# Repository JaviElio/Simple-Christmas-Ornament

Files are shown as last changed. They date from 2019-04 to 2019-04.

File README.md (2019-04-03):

# Simple-Christmas-Ornament
Christmas Ornament

Based on this project:

	- Title:	ESP8266 Christmas Ornaments!
	- Author:	Sean Hodgins
	- Link:		https://www.instructables.com/id/ESP8266-Christmas-Ornaments/

**BOM:**

(1) Attiny85

(3) WS2812

(1) DC/DC Step up converter ME2108

(1) Buzzer MLT-8530

(1) BC817

(1) SI2302

(1) Push Button

(1) [SMD AAA Batery Holder](https://www.aliexpress.com/item/5Pcs-lot-1-AAA-Battery-Holder-SMD-SMT-High-Quality-Battery-Box-With-Bronze-Pins-TBH/32795495670.html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,searchweb201602_5_10065_10068_10547_319_10891_317_10548_10696_10084_453_454_10083_10618_10307_10820_10821_10301_10303_537_536_10059_10884_10887_321_322_10103,searchweb201603_51,ppcSwitch_0&algo_expid=1f16c75a-10c3-4c96-85c8-67561e371a74-2&algo_pvid=1f16c75a-10c3-4c96-85c8-67561e371a74&transAbTest=ae803_3)

(1) Schottky Diode

(1) M7 Diode

(1) 47uF Capacitor

(1) 0.1uF Capacitor 

(1) 470 Ohm Resistor

(1) 10 kOhm Resistor

**SCHEMATIC:**

 [Schematic PDF](https://github.com/JaviElio/Simple-Christmas-Ornament/blob/master/Schematic.pdf)

**FEATURES:**

This Ornaments plays a song every time the button is pressed. Leds changes its color to the rhythm of the song.
Attiny85 goes to deep sleep to save energy.

**PICTURES**

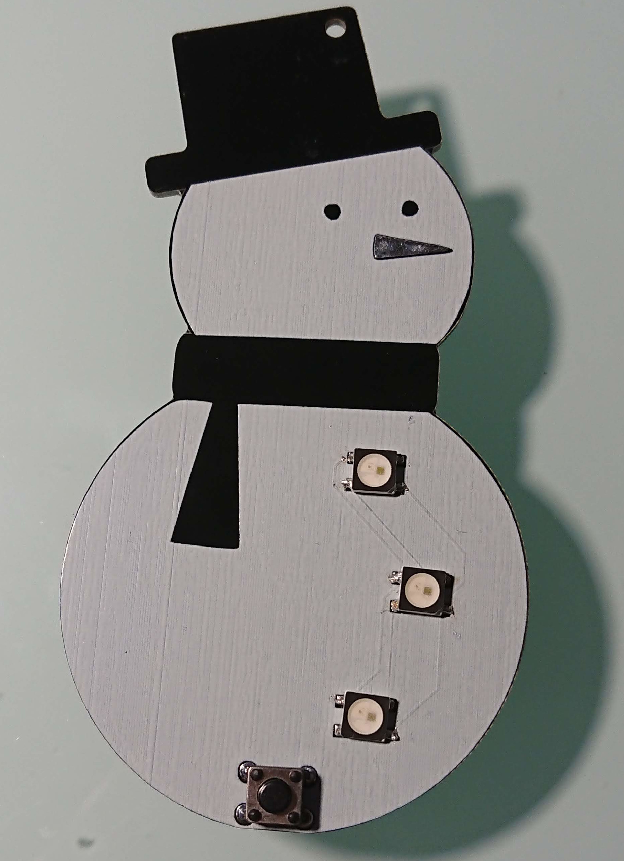
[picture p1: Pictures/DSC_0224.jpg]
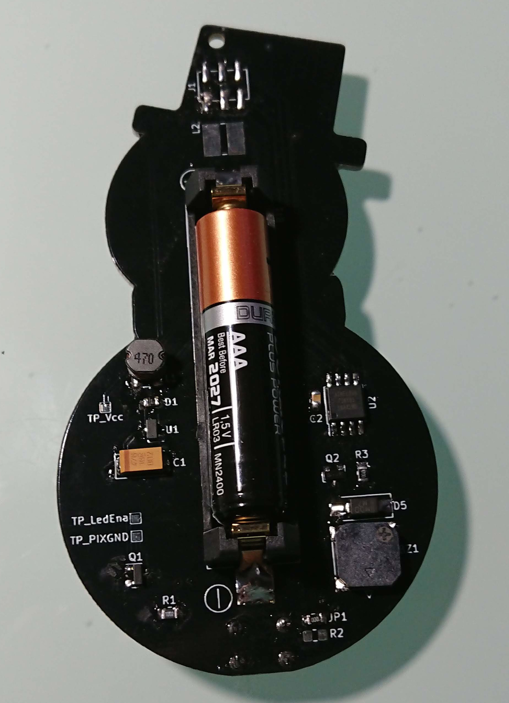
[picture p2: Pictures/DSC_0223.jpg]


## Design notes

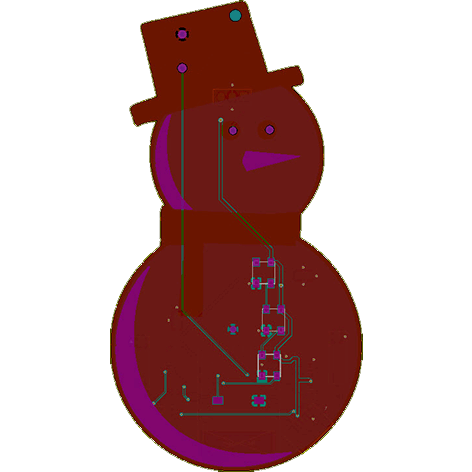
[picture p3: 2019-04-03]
Pictures/frosty.gif

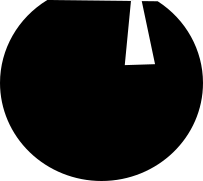
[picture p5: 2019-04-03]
Pictures/Frosty_Body.png

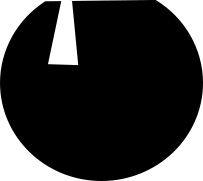
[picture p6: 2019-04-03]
Pictures/Frosty_Body.bmp

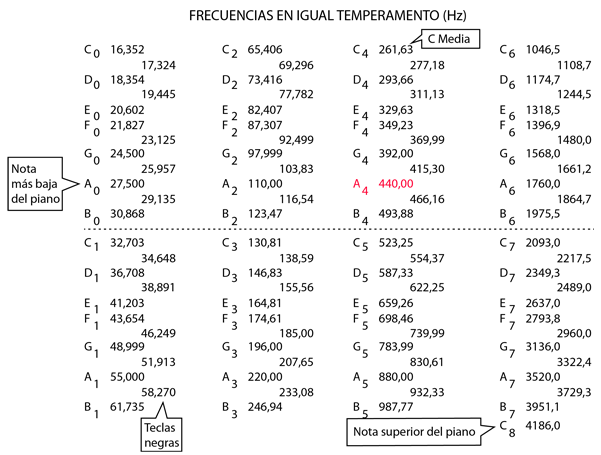
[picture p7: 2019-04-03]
Datasheets/etfreq.png

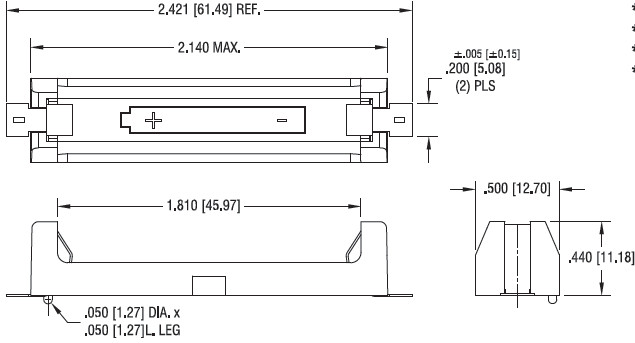
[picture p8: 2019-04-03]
Datasheets/AAA-Battery-Holder-SMD.jpg

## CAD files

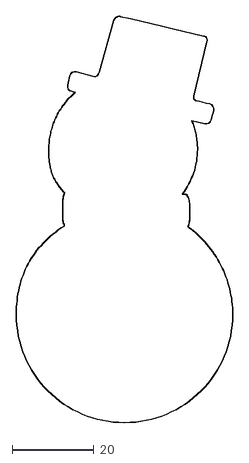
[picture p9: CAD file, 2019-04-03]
Pictures/PCB.dxf
52.8 x 99.1

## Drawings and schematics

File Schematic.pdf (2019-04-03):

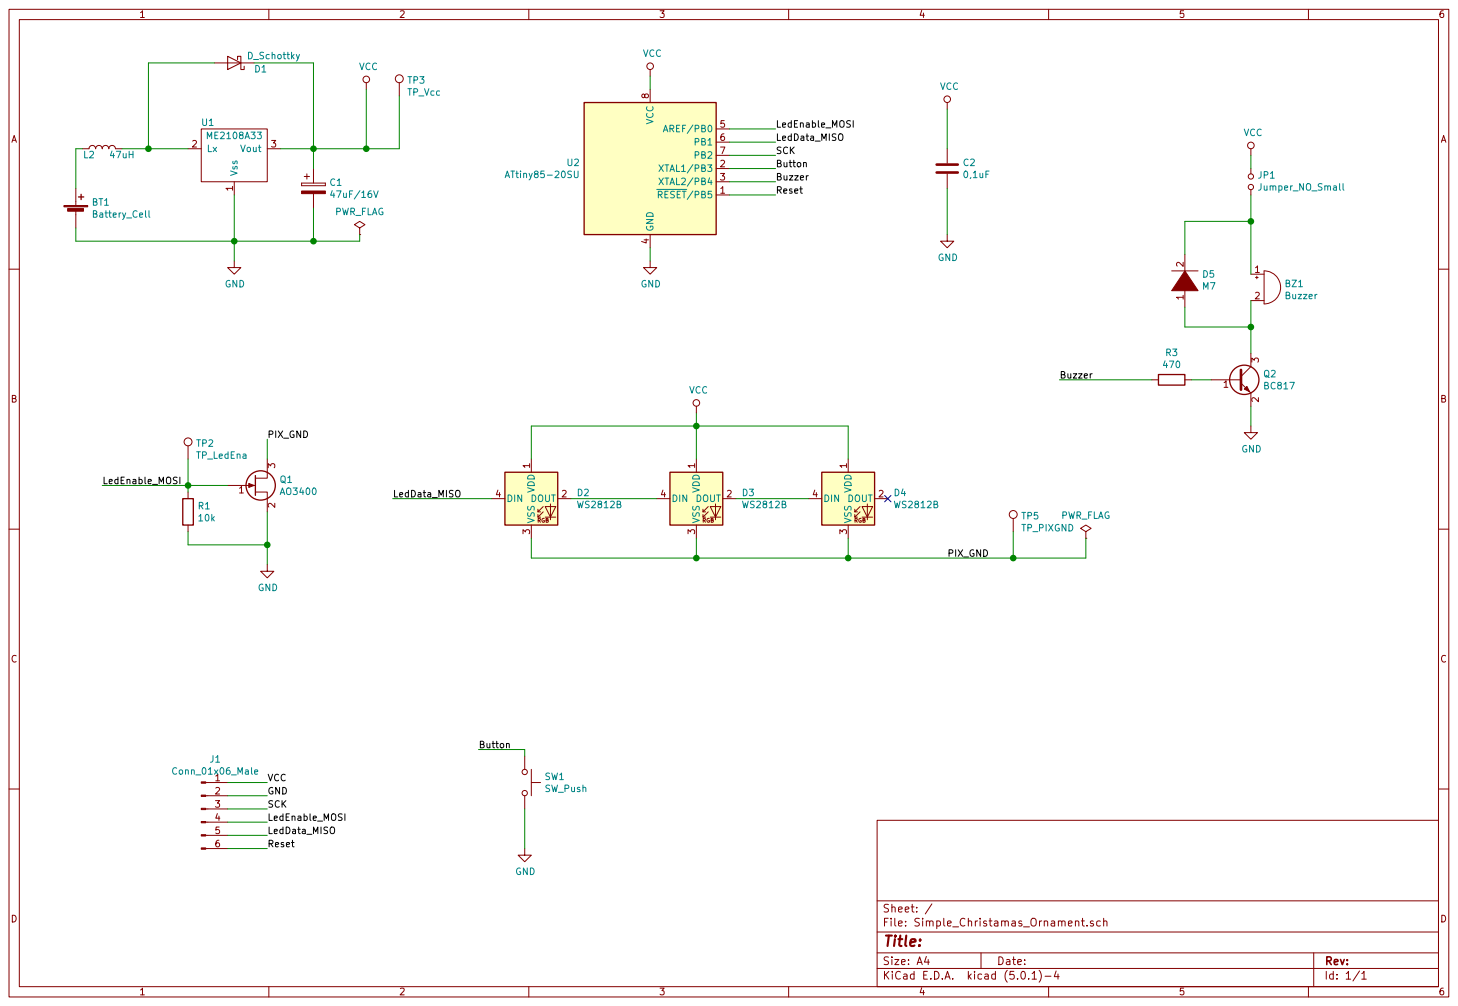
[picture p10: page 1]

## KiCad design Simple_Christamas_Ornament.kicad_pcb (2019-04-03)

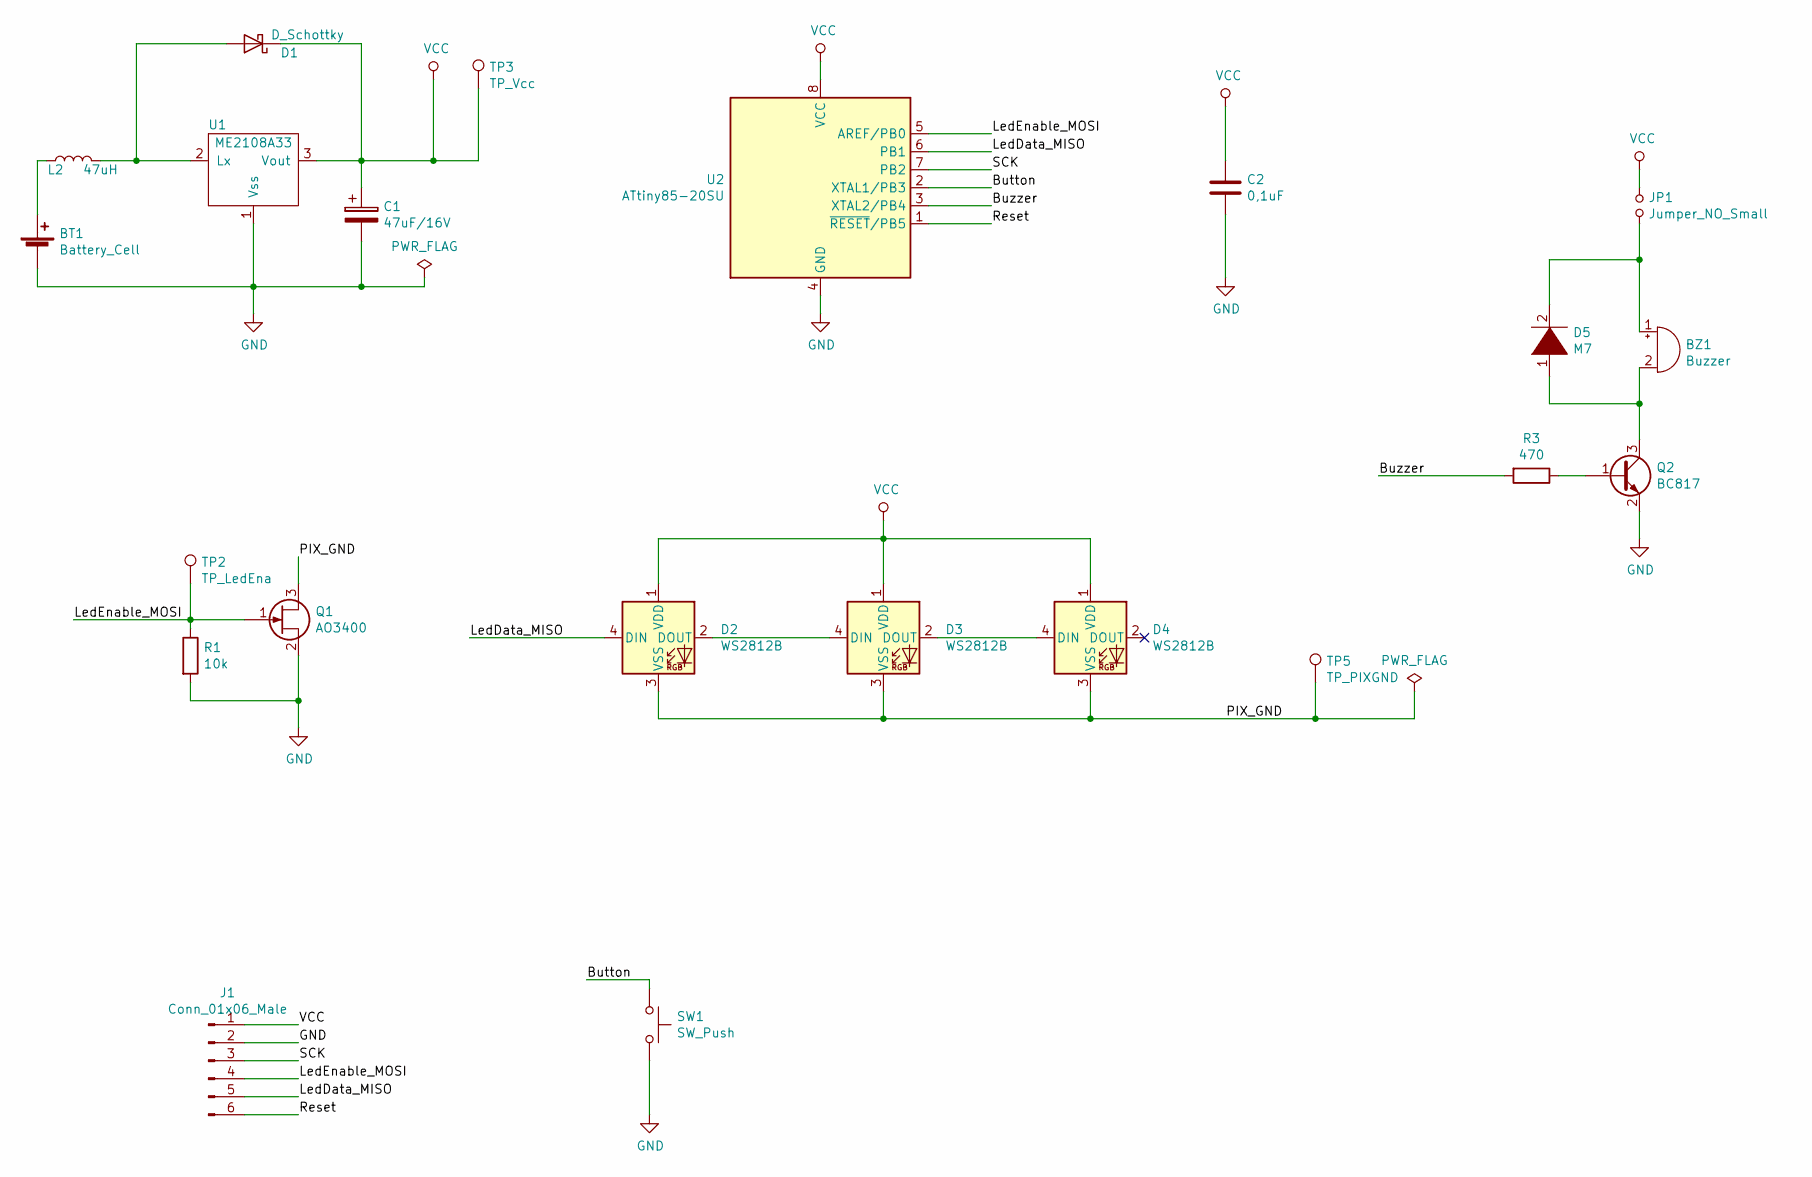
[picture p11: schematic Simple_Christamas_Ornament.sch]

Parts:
BT1: Battery_Cell; AAA_SMD_Holder
BZ1: Buzzer; Buzzer_8.5x8.5mm
C1: 47uF/16V; CP_EIA-6032-28_Kemet-C_Pad2.25x2.35mm_HandSolder
C2: 0,1uF; C_0805_2012Metric_Pad1.15x1.40mm_HandSolder
D1: D_Schottky; R_0805_2012Metric_Pad1.15x1.40mm_HandSolder
D2, D3, D4: WS2812B; LED_WS2812B_PLCC4_5.0x5.0mm_P3.2mm
D5: M7; D_SMA_Handsoldering
J1: Conn_01x06_Male; PinHeader_2x03_P2.54mm_Vertical_SMD
JP1: Jumper_NO_Small; R_0805_2012Metric_Pad1.15x1.40mm_HandSolder
L2: 47uH; Inductor_SM5845
Q1: AO3400; SOT-23_Handsoldering
Q2: BC817; SOT-23_Handsoldering
R1: 10k; R_0805_2012Metric_Pad1.15x1.40mm_HandSolder
R3: 470; R_0805_2012Metric_Pad1.15x1.40mm_HandSolder
SW1: SW_Push; SW_PUSH_6mm_H4.3mm
TP2: TP_LedEna; TestPoint_Pad_1.0x1.0mm
TP3: TP_Vcc; TestPoint_Pad_1.0x1.0mm
TP5: TP_PIXGND; TestPoint_Pad_1.0x1.0mm
U1: ME2108A33; SOT-23_Handsoldering
U2: ATtiny85-20SU; SOIJ-8_5.3x5.3mm_P1.27mm

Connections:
/Button: SW1.1, U2.2 (XTAL1/PB3)
/Buzzer: R3.2, U2.3 (XTAL2/PB4)
/LedData_MISO: D2.4 (DIN), J1.5, U2.6 (PB1)
/LedEnable_MOSI: J1.4, Q1.1 (G), R1.1, TP2.1, U2.5 (AREF/PB0)
/PIX_GND: D2.3 (VSS), D3.3 (VSS), D4.3 (VSS), Q1.3 (D), TP5.1
/Reset: J1.6, U2.1 (~RESET~/PB5)
/SCK: J1.3, U2.7 (PB2)
GND: BT1.2 (-), C1.2, C2.2, J1.2, Q1.2 (S), Q2.2 (E), R1.2, SW1.2, U1.1 (Vss), U2.4 (GND)
unnamed: BT1.1 (+), L2.1
unnamed: BZ1.1 (-), D5.2 (A), JP1.1
unnamed: BZ1.2 (+), D5.1 (K), Q2.3 (C)
unnamed: D1.2 (A), L2.2, U1.2 (Lx)
unnamed: D2.2 (DOUT), D3.4 (DIN)
unnamed: D3.2 (DOUT), D4.4 (DIN)
unnamed: Q2.1 (B), R3.1
VCC: C1.1, C2.1, D1.1 (K), D2.1 (VDD), D3.1 (VDD), D4.1 (VDD), J1.1, JP1.2, TP3.1, U1.3 (Vout), U2.8 (VCC)

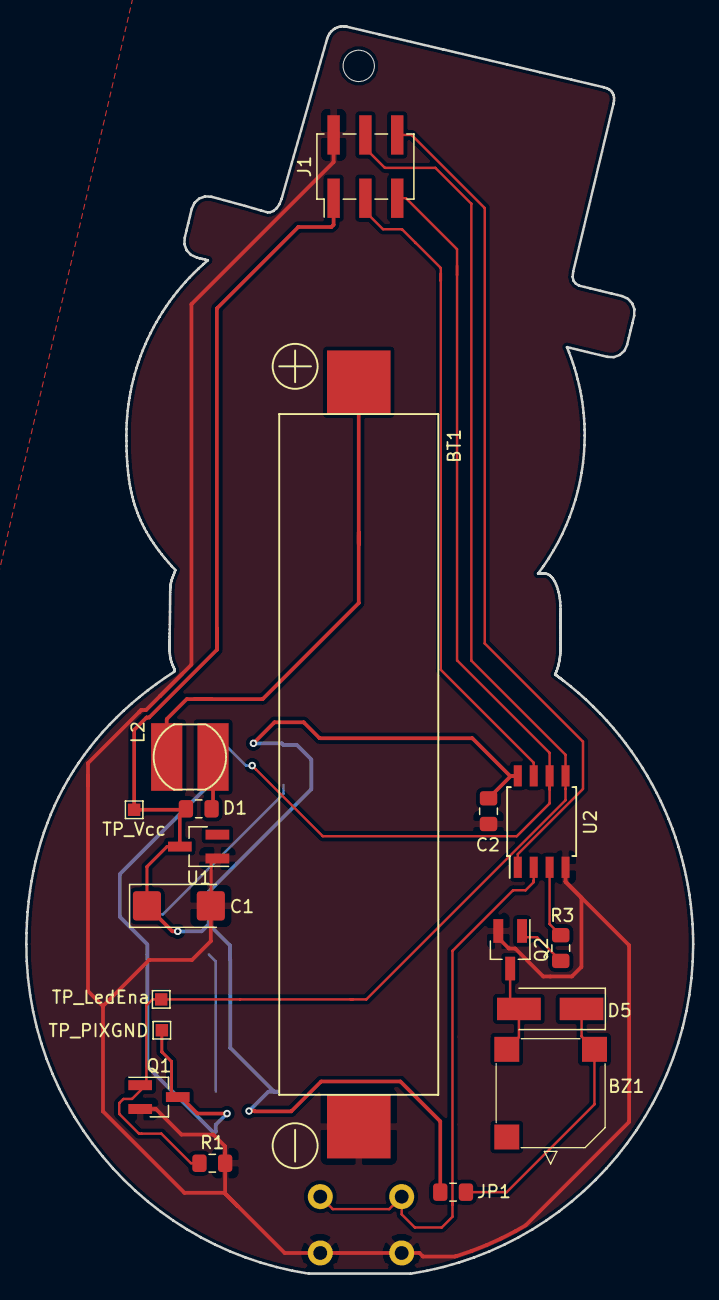
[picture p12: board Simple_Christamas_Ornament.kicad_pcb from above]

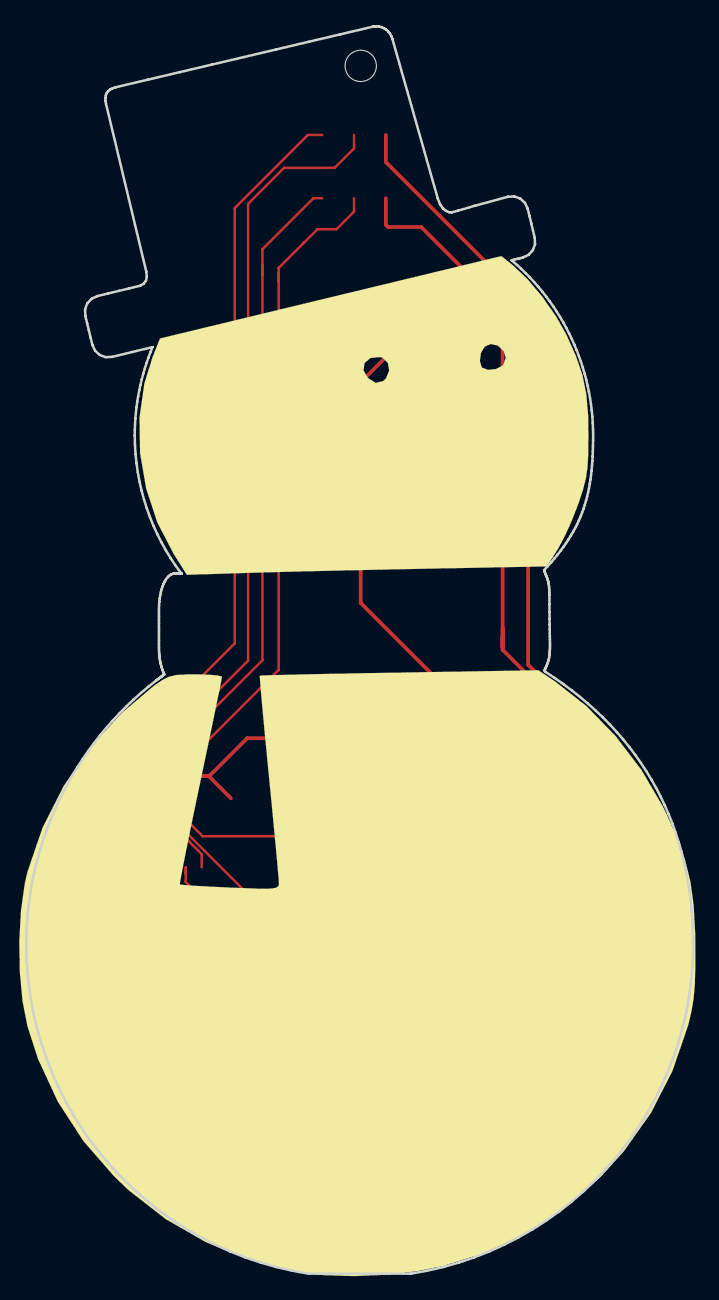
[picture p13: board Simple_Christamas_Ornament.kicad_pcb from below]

Board: 2 copper layers, 53.2 x 99.6 mm, 22 parts (4 on the bottom side), 16 nets.

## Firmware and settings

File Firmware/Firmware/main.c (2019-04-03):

/*
 * Firmware.c
 *
 * Created: 22/01/2019 19:30:02
 * Author : javie
 */ 

#define F_CPU 8000000UL

#include <avr/io.h>
#include <avr/interrupt.h>
#include <util/delay.h>
#include <avr/sleep.h>
#include <avr/pgmspace.h>

//#define CYCLES_PER_NS	(F_CPU/1000000000L)					// 0,008 -> 0
#define NS_PER_CYCLE	(1000000000UL/F_CPU)				// 125ns/cycle -> 62				
//#define NS_TO_CYCLES(n)	(CYCLES_PER_NS*(n))	
#define NS_TO_CYCLES(n)	((n)/NS_PER_CYCLE)					 
#define DELAYCYCLES(n)	(((n)>0) ? __builtin_avr_delay_cycles(n) : __builtin_avr_delay_cycles(0))

// Notes
#define NOTE_C	237
#define NOTE_CS	224
#define NOTE_D	212
#define NOTE_DS	199
#define NOTE_E	188
#define NOTE_F	178
#define NOTE_FS	167
#define NOTE_G	158
#define NOTE_GS	149
#define NOTE_A	141
#define NOTE_AS	133
#define NOTE_B	125

// WS2812B time constraints
#define TOH	400
#define TOL	900
#define T1H	900
#define T1L	600
#define RES	10000	

uint8_t PIXELS = 3;

const uint8_t color[25][3] = {
	{0,0,100},
	{200,0,200},
	{0,100,0},
	{100,200,200},
	{200,200,100},
	{0,100,100},
	{0,200,0},
	{0,200,100},
	{100,100,100},
	{100,0,0},
	{100,0,100},
	{0,0,200},
	{100,100,0},
	{100,100,200},
	{0,100,200},
	{100,200,0},
	{100,0,200},
	{100,200,100},
	{200,0,0},
	{200,0,100},
	{200,100,0},
	{0,200,200},
	{200,100,200},
	{200,200,0},
	{200,100,100},
	};


uint8_t colorIndex = 0;

typedef enum {Jingle, Frosty, Merry, Deck, LastSong} song;
song	toSong;

const uint8_t  Jinglelength   = 27;
const uint8_t PROGMEM Jinglenotes[27]  = {NOTE_B, NOTE_B, NOTE_B, NOTE_B, NOTE_B, NOTE_B, NOTE_B, NOTE_D, NOTE_G, NOTE_A, NOTE_B, 0, NOTE_C, NOTE_C, NOTE_C, NOTE_C, NOTE_C, NOTE_B,
						   NOTE_B, NOTE_B, NOTE_B, NOTE_A, NOTE_A, NOTE_B, NOTE_A, NOTE_D, 0};
const uint8_t PROGMEM JingleOctave[27] = {     4,      4,      4,      4,      4,      4,      4,      5,      4,      4,      4, 0,      5,      5,      5,      5,      5,      4,
								4,      4,      4,      4,      4,      4,      4,      5, 0};
const uint8_t PROGMEM Jinglebeats[27]  = {     2,      2,      4,      2,      2,      4,      2,      2,      2,      2,      4, 4,      2,      2,      2,      2,      2,      2,
								2,      2,      2,      2,      2,      2,      4,      4, 4};


const uint8_t Frostylength   = 31;	
const uint8_t PROGMEM Frostynotes[31]  = {NOTE_G, NOTE_E, NOTE_F, NOTE_G, NOTE_C, NOTE_B, NOTE_C, NOTE_D, NOTE_C, NOTE_B, NOTE_A, NOTE_G,      0, NOTE_B, NOTE_C, NOTE_D, 
						  NOTE_C, NOTE_B, NOTE_A, NOTE_A, NOTE_G, NOTE_C, NOTE_E, NOTE_G, NOTE_A, NOTE_G, NOTE_F, NOTE_E, NOTE_D, NOTE_C,      0};
const uint8_t PROGMEM FrostyOctave[31] = {     4,      4,		4,      4,      5,      4,      5,		5,      5,      4,      4,      4,      0,      4,      5,      5,
							   5,      4,      4,      4,      4,      5,      4,      4,      4,      4,      4,      4,      4,      4,      0};
const uint8_t PROGMEM Frostybeats[31]  = {     4,      4,      1,      2,      4,      1,      1,      2,      2,      2,      2,      4,      2,      1,      1,      2, 
	                           2,      2,      1,      1,      2,      2,      2,      1,      1,      2,      2,      2,      2,      4,      4};


const uint8_t Mariolength   = 13;
const uint8_t PROGMEM Marionotes[13]  = {NOTE_E,NOTE_E,0,NOTE_E,0,NOTE_C,NOTE_E,0,NOTE_G,0,0,0,NOTE_G};
const uint8_t	PROGMEM MarioOctave[13] = {     5,     5,0,     5,0,     5,     5,0,     5,0,0,0,     4};
const uint8_t PROGMEM Mariobeats[13]  = {     4,     4,4,     4,4,     4,     4,4,     4,4,4,4,     4};



const uint8_t  Merrylength   = 31;
const uint8_t PROGMEM Merrynotes[31]  = {NOTE_D, NOTE_G, NOTE_G, NOTE_A, NOTE_G, NOTE_FS, NOTE_E, NOTE_E, NOTE_E, NOTE_A, NOTE_A, NOTE_B,  NOTE_A, NOTE_G, NOTE_FS, NOTE_D, 
						  NOTE_D, NOTE_B, NOTE_B, NOTE_C, NOTE_B,  NOTE_A, NOTE_G, NOTE_E, NOTE_D, NOTE_D, NOTE_E, NOTE_A, NOTE_FS, NOTE_G,       0};
const uint8_t PROGMEM MerryOctave[31] = {     4,      4,      4,      4,      4,       4,      4,      4,      4,      4,      4,      4,       4,      4,       4,      4,
	                           4,      4,      4,      5,      4,       4,      4,      4,      4,      4,      4,      4,       4,      4,       0};	
const uint8_t PROGMEM Merrybeats[31]  = {     2,      2,      1,      1,      1,       1,      2,      2,      2,      2,      1,      1,       1,      1,       2,      2, 
	                           2,      2,      1,      1,      1,       1,      2,      2,      1,      1,      2,      2,       2,      4,       4};


const uint8_t Decklength    = 18;
const uint8_t PROGMEM Decknotes[18]   = {NOTE_G, NOTE_F, NOTE_E, NOTE_D, NOTE_C, NOTE_D, NOTE_E, NOTE_C, NOTE_D, NOTE_E, NOTE_F, NOTE_D, NOTE_E, NOTE_D, NOTE_C, NOTE_B, NOTE_C, 0};
const uint8_t PROGMEM Deckocatave[18] =	{     4,      4,      4,      4,      4,      4,      4,      4,      4,      4,      4,      4,      4,      4,      4,      3,      4, 0};
const uint8_t PROGMEM Deckbeats[18]   = {     4,      1,      2,      2,      2,      2,      2,      2,      1,      1,      1,      1,      4,      1,      2,      2,      4, 4};


uint8_t	buttonCounter ;


void sendBit(uint8_t xbit){
	
	if (xbit == 0){
	
		//cli();
		PORTB |= (1 << PB1);
		DELAYCYCLES(NS_TO_CYCLES(TOH)-2);
		PORTB &= ~(1 << PB1);
		//sei();
		DELAYCYCLES(NS_TO_CYCLES(TOL)-1);
		
	}
	else {
		
		PORTB |= (1 << PB1);
		DELAYCYCLES(NS_TO_CYCLES(T1H)-2);
		PORTB &= ~(1 << PB1);
		DELAYCYCLES(NS_TO_CYCLES(T1L)-1);
		
	}
}

void sendByte(uint8_t xByte) {
	
	for (uint8_t i=0; i<8; i++)
	{
		//sendBit(xByte & (0x01 << i));

		if (xByte & (0x01 << i))
		{
			
			PORTB |= (1 << PB1);
			DELAYCYCLES(NS_TO_CYCLES(T1H)-2);
			PORTB &= ~(1 << PB1);
			DELAYCYCLES(NS_TO_CYCLES(T1L)-4);

		}
		else
		{
			//cli();
			PORTB |= (1 << PB1);
			DELAYCYCLES(NS_TO_CYCLES(TOH)-2);
			PORTB &= ~(1 << PB1);
			//sei();
			DELAYCYCLES(NS_TO_CYCLES(TOL)-4);
		}
		
	}
}

void	sendLatch(void) {
	DELAYCYCLES(NS_TO_CYCLES(RES));
}

void	setPixel ( uint8_t r, uint8_t g, uint8_t b) {
	
 		sendByte(g);
 		sendByte(r);
 		sendByte(b);

}


void	showColor() {
	
	for (uint8_t i=0; i<PIXELS; i++)
	{
		if (colorIndex>=25) colorIndex = 0;
		setPixel(color[colorIndex][0],color[colorIndex][1],color[colorIndex][2]);
		colorIndex++;
	}
}

void switchOffLeds() {

	PORTB &= ~(1 << PB1);	// OUTPUT -> 0
	DDRB  &= ~(1 << PB1);   // PB1->INPUT (Hi-Z)
	PORTB &= ~(1 << PB0);	// Switch off MOSFET
}

void switchOnLeds() {
	
	PORTB |= (1 << PB0);	// Switch on MOSFET
	_delay_ms(1);
	DDRB  |= (1 << PB1);    // PB1 -> OUTPUT
	PORTB &= ~(1 << PB1);	// OUTPUT -> 0
}


void playTone(uint8_t tone, uint8_t octave) {

	TCCR1  = 0x90;						// clear TCNT1 on compare match
	OCR1C = tone-1;						// Set compare register
	TCCR1 |=  (11-octave);				// Set prescaler / start counter
	if (tone==0) TCCR1 = 0x90;			// Stop timer1

}



void playMario (void) {
	
	switchOnLeds();
	
	GTCCR |= (1 << COM1B0);																		// Connect timer to PB4 and toggle on CTC
	
	for (uint8_t i=0; i<Mariolength; i++) {

		if (pgm_read_byte_near(Marionotes + i) != 0)	showColor();							// Change led colors if note changes
		playTone(pgm_read_byte_near(Marionotes + i), pgm_read_byte_near(MarioOctave + i));		// Play note
		for(uint8_t j=0; j<pgm_read_byte_near(Mariobeats + i); j++) _delay_ms(35);				// delay to keep the note

		TCCR1 = 0x00;																			// Stops timer. No idea why 0x90 does not work here.
		_delay_ms(35);																			// Pause between notes.
	}
	
	GTCCR &= ~( 1 << COM1B0);																	// Disconnect from PB4
	PORTB &= ~( 1 << PB4);																		// Switch off PB4
	
	switchOffLeds();
}


void	playSong (const uint8_t *note, const uint8_t *octave, const uint8_t *beats, const uint8_t songLenght) {
	
	switchOnLeds();
	
	GTCCR |= (1 << COM1B0);																	// Connect timer to PB4 and toggle on CTC
		
	for (uint8_t i=0; i<songLenght; i++) {
		
		if (pgm_read_byte_near(note + i) != 0)	showColor();								// Change led colors if note changes
		playTone(pgm_read_byte_near(note + i), pgm_read_byte_near(octave + i));				// Play note	
		for(uint8_t j=0; j<pgm_read_byte_near(beats + i); j++) _delay_ms(100);				// Delay to keep note
					
		TCCR1 = 0x00;																		// Stops timer. No idea why 0x90 does note work here.
		_delay_ms(50);																		// Pause between notes
	}
		
	GTCCR &= ~( 1 << COM1B0);																// Disconnect from PB4
	PORTB &= ~( 1 << PB4);																	// Switch off PB4
	
	switchOffLeds();
	
}


ISR (PCINT0_vect) {

	_delay_ms(200);
	while( !(PINB & ( 1 << PINB3 )));
	buttonCounter++;
	
}


int main(void)
{
	
	// Setup I/O
	DDRB |= (1 << PB1);					// Neopixel Data Output
	DDRB |= (1 << PB0);					// Neopixel enable
	DDRB |= (1 << PB4);					// Buzzer output
	DDRB &= ~(1 << PB3);				// Button input
	PORTB |= (1 << PB3);				// Pull-up resistor


	switchOffLeds();
			
	// Setup interrupt on PB3
	PCMSK |= ( 1 << PCINT3);		// Enable Pin Change Interrupt on PB3
	GIMSK |= ( 1 << PCIE);			// Enable Pin Change Interrupts
	sei();
	
	// Setup power savings
	ADCSRA = 0;						// Disable ADC
	PRR |= (1 << PRADC) | (1 << PRTIM0) | ( 1 << PRUSI) ;			// Power off ADC, USI, TIMER0
	set_sleep_mode(SLEEP_MODE_PWR_DOWN);


    while (1) 
    {


 		sei();
		sleep_mode();					// Sleep.....
 		cli();


		if ( ((buttonCounter/33) > 0) && (buttonCounter%33 == 0)  ) playMario();							// Play Mario when button is pressed 33 times
		else {
			
			if (toSong == Jingle) playSong(Jinglenotes, JingleOctave, Jinglebeats, Jinglelength);
			if (toSong == Frosty) playSong(Frostynotes, FrostyOctave, Frostybeats, Frostylength);
			if (toSong == Deck)   playSong(Decknotes, Deckocatave, Deckbeats, Decklength);
			if (toSong == Merry)  playSong(Merrynotes, MerryOctave, Merrybeats, Merrylength);
			
			toSong = toSong + 1;	// Next song
			if (toSong == LastSong) toSong = Jingle;	// Return to first song 
		}
		
					
		
	}
}

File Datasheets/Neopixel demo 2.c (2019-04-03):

/*
 This is an example of how simple driving a Neopixel can be
 This code is optimized for understandability and changability rather than raw speed
 More info at http://wp.josh.com/2014/05/11/ws2812-neopixels-made-easy/
*/

// Change this to be at least as long as your pixel string (too long will work fine, just be a little slower)

#define PIXELS 96*11  // Number of pixels in the string

// These values depend on which pin your string is connected to and what board you are using 
// More info on how to find these at http://www.arduino.cc/en/Reference/PortManipulation

// These values are for the pin that connects to the Data Input pin on the LED strip. They correspond to...

// Arduino Yun:     Digital Pin 8
// DueMilinove/UNO: Digital Pin 12
// Arduino MeagL    PWM Pin 4

// You'll need to look up the port/bit combination for other boards. 

// Note that you could also include the DigitalWriteFast header file to not need to to this lookup.

#define PIXEL_PORT  PORTB  // Port of the pin the pixels are connected to
#define PIXEL_DDR   DDRB   // Port of the pin the pixels are connected to
#define PIXEL_BIT   4      // Bit of the pin the pixels are connected to

// These are the timing constraints taken mostly from the WS2812 datasheets 
// These are chosen to be conservative and avoid problems rather than for maximum throughput 

#define T1H  900    // Width of a 1 bit in ns
#define T1L  600    // Width of a 1 bit in ns

#define T0H  400    // Width of a 0 bit in ns
#define T0L  900    // Width of a 0 bit in ns

#define RES 6000    // Width of the low gap between bits to cause a frame to latch

// Here are some convience defines for using nanoseconds specs to generate actual CPU delays

#define NS_PER_SEC (1000000000L)          // Note that this has to be SIGNED since we want to be able to check for negative values of derivatives

#define CYCLES_PER_SEC (F_CPU)

#define NS_PER_CYCLE ( NS_PER_SEC / CYCLES_PER_SEC )

#define NS_TO_CYCLES(n) ( (n) / NS_PER_CYCLE )

// Actually send a bit to the string. We must to drop to asm to enusre that the complier does
// not reorder things and make it so the delay happens in the wrong place.

inline void sendBit( bool bitVal ) {
  
    if (  bitVal ) {				// 0 bit
      
		asm volatile (
			"sbi %[port], %[bit] \n\t"				// Set the output bit
			".rept %[onCycles] \n\t"                                // Execute NOPs to delay exactly the specified number of cycles
			"nop \n\t"
			".endr \n\t"
			"cbi %[port], %[bit] \n\t"                              // Clear the output bit
			".rept %[offCycles] \n\t"                               // Execute NOPs to delay exactly the specified number of cycles
			"nop \n\t"
			".endr \n\t"
			::
			[port]		"I" (_SFR_IO_ADDR(PIXEL_PORT)),
			[bit]		"I" (PIXEL_BIT),
			[onCycles]	"I" (NS_TO_CYCLES(T1H) - 2),		// 1-bit width less overhead  for the actual bit setting, note that this delay could be longer and everything would still work
			[offCycles] 	"I" (NS_TO_CYCLES(T1L) - 2)			// Minimum interbit delay. Note that we probably don't need this at all since the loop overhead will be enough, but here for correctness

		);
                                  
    } else {					// 1 bit

		// **************************************************************************
		// This line is really the only tight goldilocks timing in the whole program!
		// **************************************************************************


		asm volatile (
			"sbi %[port], %[bit] \n\t"				// Set the output bit
			".rept %[onCycles] \n\t"				// Now timing actually matters. The 0-bit must be long enough to be detected but not too long or it will be a 1-bit
			"nop \n\t"                                              // Execute NOPs to delay exactly the specified number of cycles
			".endr \n\t"
			"cbi %[port], %[bit] \n\t"                              // Clear the output bit
			".rept %[offCycles] \n\t"                               // Execute NOPs to delay exactly the specified number of cycles
			"nop \n\t"
			".endr \n\t"
			::
			[port]		"I" (_SFR_IO_ADDR(PIXEL_PORT)),
			[bit]		"I" (PIXEL_BIT),
			[onCycles]	"I" (NS_TO_CYCLES(T0H) - 2),
			[offCycles]	"I" (NS_TO_CYCLES(T0L) - 2)

		);
      
    }
    
    // Note that the inter-bit gap can be as long as you want as long as it doesn't exceed the 5us reset timeout (which is A long time)
    // Here I have been generous and not tried to squeeze the gap tight but instead erred on the side of lots of extra time.
    // This has thenice side effect of avoid glitches on very long strings becuase 

    
}  

  
inline void sendByte( unsigned char byte ) {
    
    for( unsigned char bit = 0 ; bit < 8 ; bit++ ) {
      
      sendBit( bitRead( byte , 7 ) );                // Neopixel wants bit in highest-to-lowest order
                                                     // so send highest bit (bit #7 in an 8-bit byte since they start at 0)
      byte <<= 1;                                    // and then shift left so bit 6 moves into 7, 5 moves into 6, etc
      
    }           
} 

/*
  The following three functions are the public API:
  
  ledSetup() - set up the pin that is connected to the string. Call once at the begining of the program.  
  sendPixel( r g , b ) - send a single pixel to the string. Call this once for each pixel in a frame.
  show() - show the recently sent pixel on the LEDs . Call once per frame. 
  
*/


// Set the specified pin up as digital out

void ledsetup() {
  
  bitSet( PIXEL_DDR , PIXEL_BIT );
  
}

inline void sendPixel( unsigned char r, unsigned char g , unsigned char b )  {  
  
  sendByte(g);          // Neopixel wants colors in green then red then blue order
  sendByte(r);
  sendByte(b);
  
}


// Just wait long enough without sending any bots to cause the pixels to latch and display the last sent frame

void show() {
	_delay_us( (RES / 1000UL) + 1);				// Round up since the delay must be _at_least_ this long (too short might not work, too long not a problem)
}


/*
  That is the whole API. What follows are some demo functions rewriten from the AdaFruit strandtest code...
  
  https://github.com/adafruit/Adafruit_NeoPixel/blob/master/examples/strandtest/strandtest.ino
  
  Note that we always turn off interrupts while we are sending pixels becuase an interupt
  could happen just when we were in the middle of somehting time sensitive.
  
  If we wanted to minimize the time interrupts were off, we could instead 
  could get away with only turning off interrupts just for the very brief moment 
  when we are actually sending a 0 bit (~1us), as long as we were sure that the total time 
  taken by any interrupts + the time in our pixel generation code never exceeded the reset time (5us).
  
*/


// Display a single color on the whole string

void showColor( unsigned char r , unsigned char g , unsigned char b ) {
  
  cli();  
  for( int p=0; p<PIXELS; p++ ) {
    sendPixel( r , g , b );
  }
  sei();
  show();
  
}
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

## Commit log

2019-04-03 First Upload
    [Notes.xlsx, PCB.dxf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]
2019-04-03 Schematic and excel file uploaded
    [Notes.xlsx, Timer Calculations.xlsx]
